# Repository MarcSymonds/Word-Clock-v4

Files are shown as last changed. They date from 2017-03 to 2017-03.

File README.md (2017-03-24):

# Word-Clock-v4
Version 4 of my Word Clock. Now uses an Arduino and WS2812 RGB LEDs.

My original Word Clock used a PICAXE microcontroller and plain white LEDs to show the time.

This version is a complete redesign and uses and Arduino Nano and WS2812B RGD LEDs to show the time in various colours.

To hold the LEDs, I used Wings3D to create a 11x5 frame to hold 55 LEDs (the clock uses 110 LEDs), and printed that on a 3D printer.

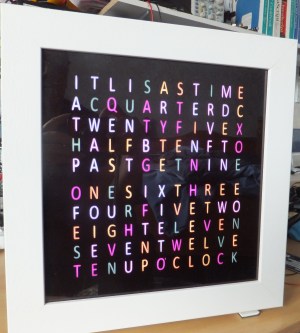
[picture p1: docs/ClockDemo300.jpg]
Clock in test mode

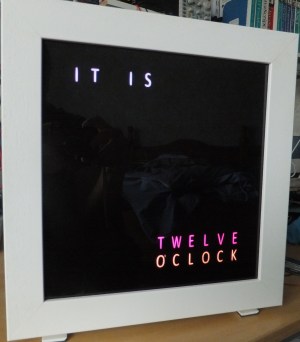
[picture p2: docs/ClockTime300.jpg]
Clock showing the current time in words

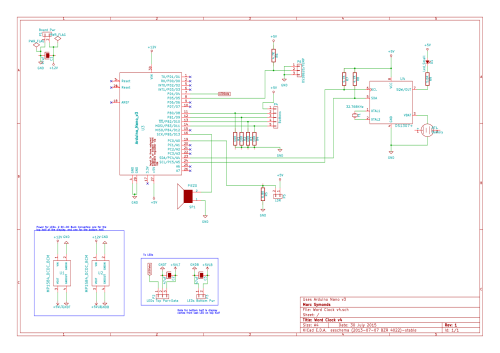
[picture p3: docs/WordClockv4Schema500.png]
KiCAD Schema


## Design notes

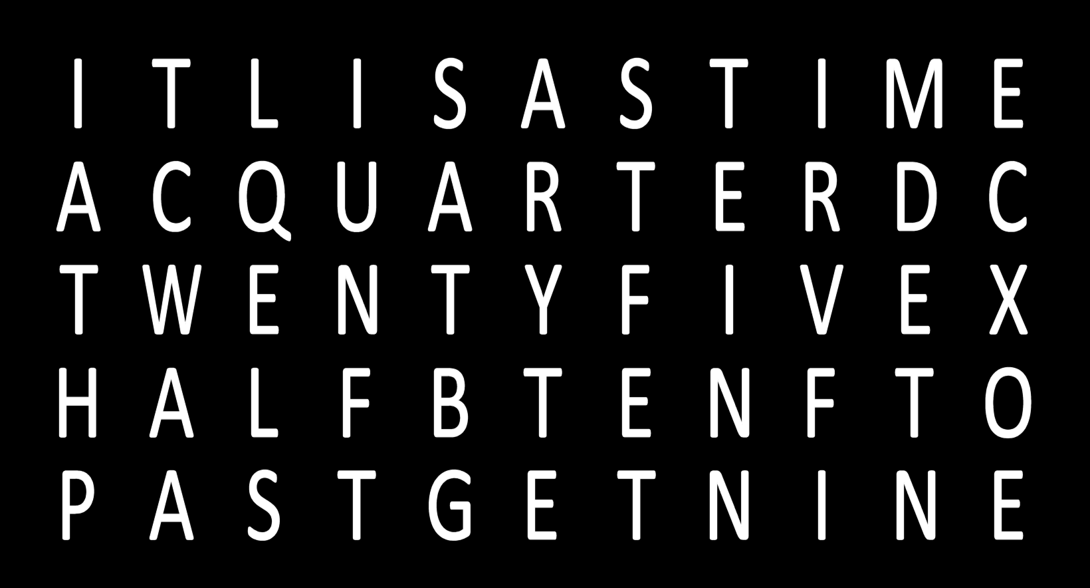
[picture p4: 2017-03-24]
Images/Word Clock mask - top.png

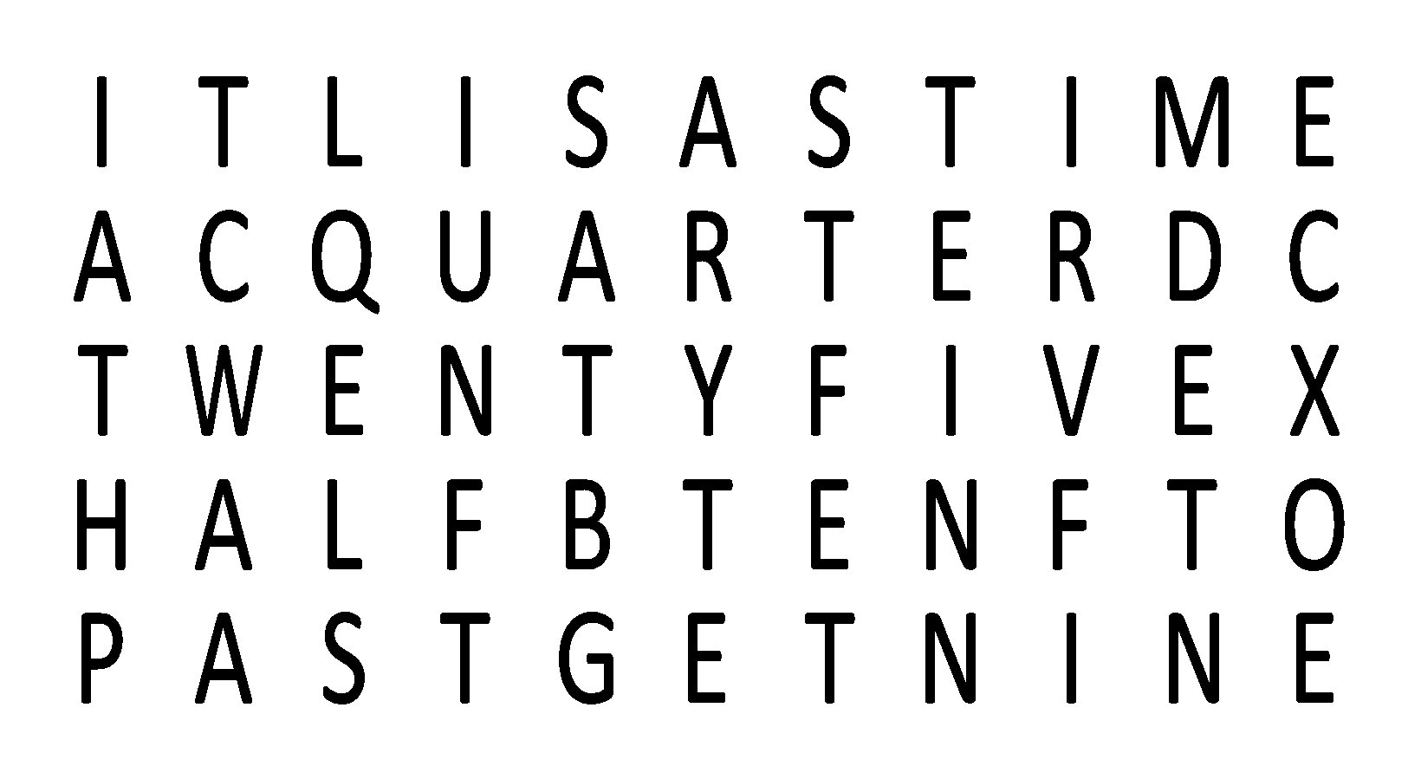
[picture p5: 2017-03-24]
Images/Word Clock mask - top.jpg

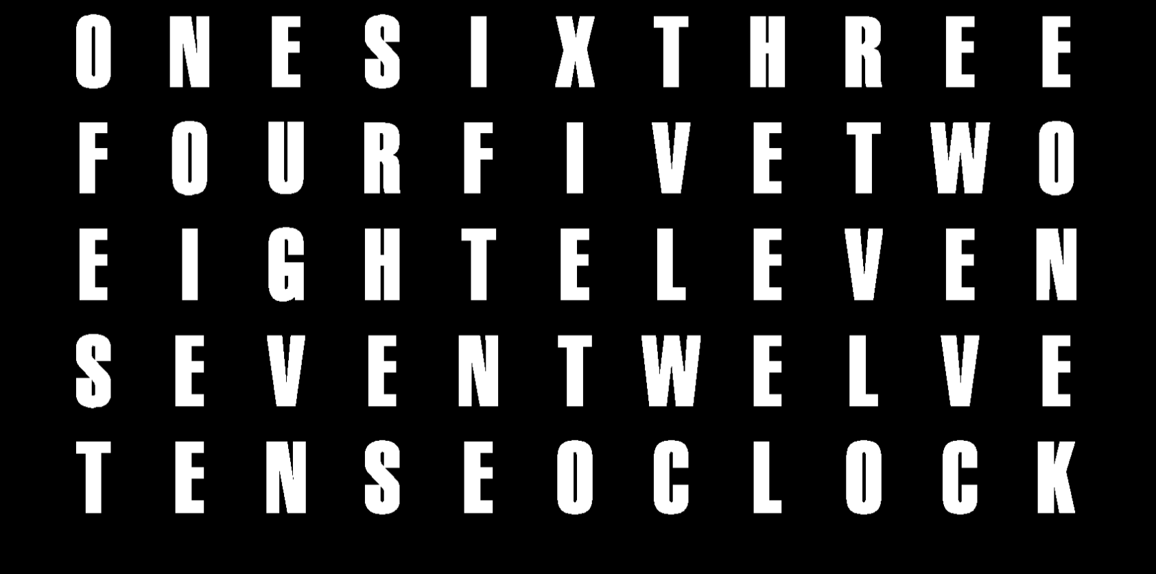
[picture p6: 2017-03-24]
Images/Word Clock mask - bottom.png

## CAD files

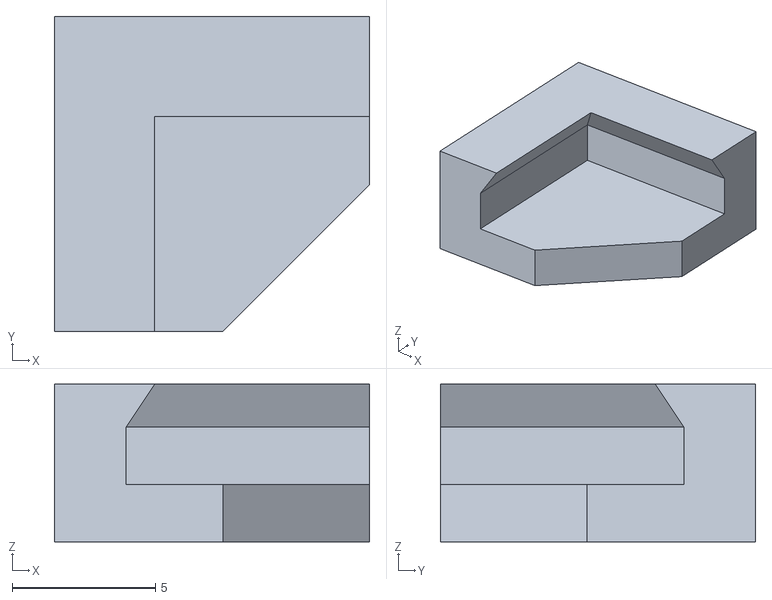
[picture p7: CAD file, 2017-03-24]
3D Objects/PCB Holder.stl
11.0 x 11.0 x 5.50

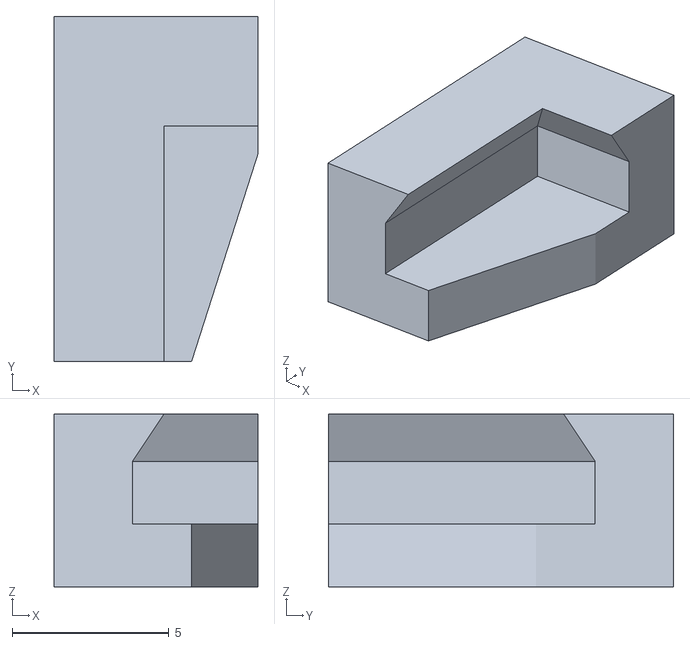
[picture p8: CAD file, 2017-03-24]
3D Objects/PCB Holder 3.stl
6.50 x 11.0 x 5.50

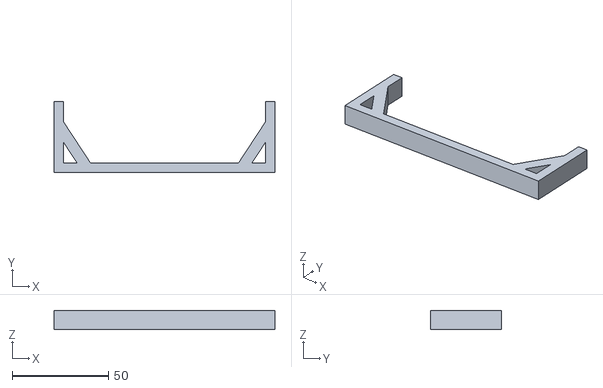
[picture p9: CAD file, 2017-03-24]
3D Objects/LED Holder Support.stl
115.0 x 37.0 x 10.0

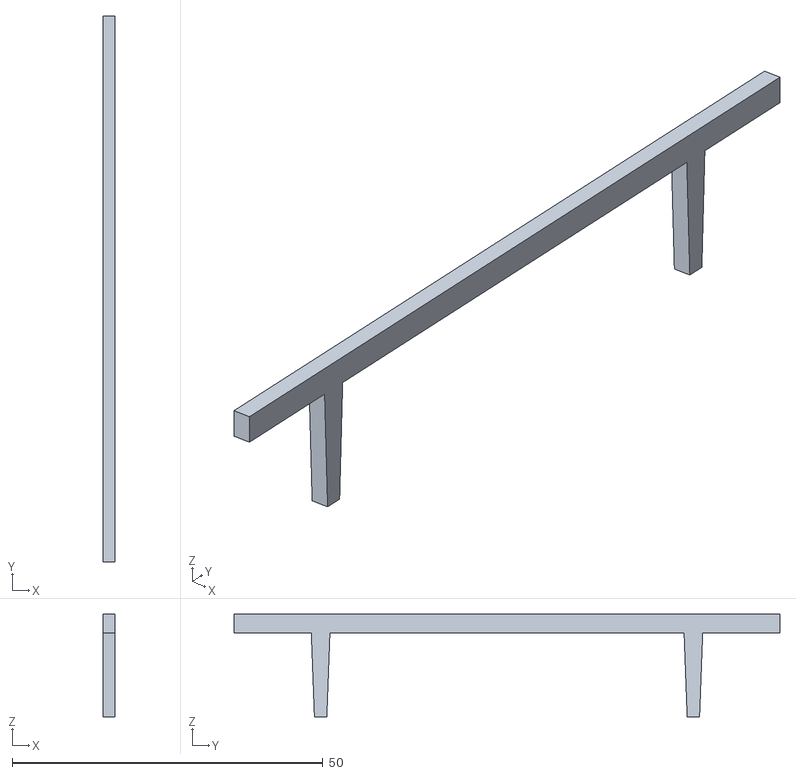
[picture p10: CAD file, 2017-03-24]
3D Objects/LED Holder - Bottom.stl
2.00 x 87.9 x 16.5

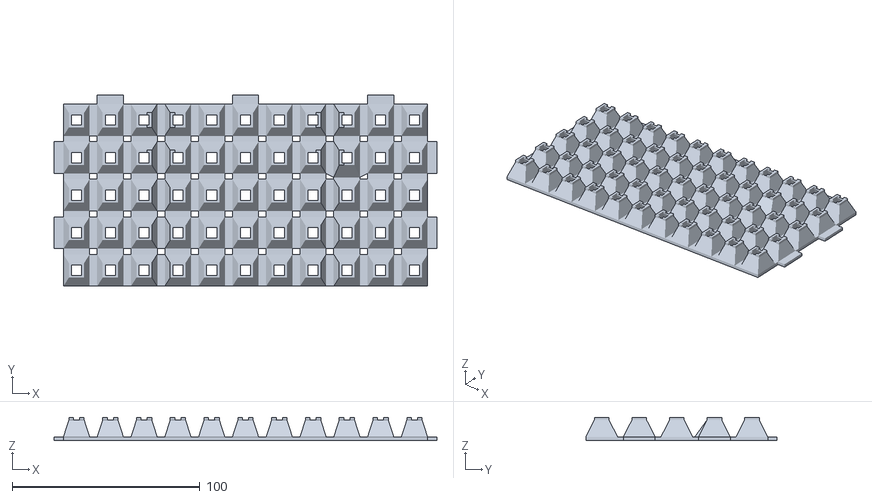
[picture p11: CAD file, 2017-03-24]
3D Objects/LED Holder - Top (Ext Q).stl
204.0 x 102.0 x 12.5

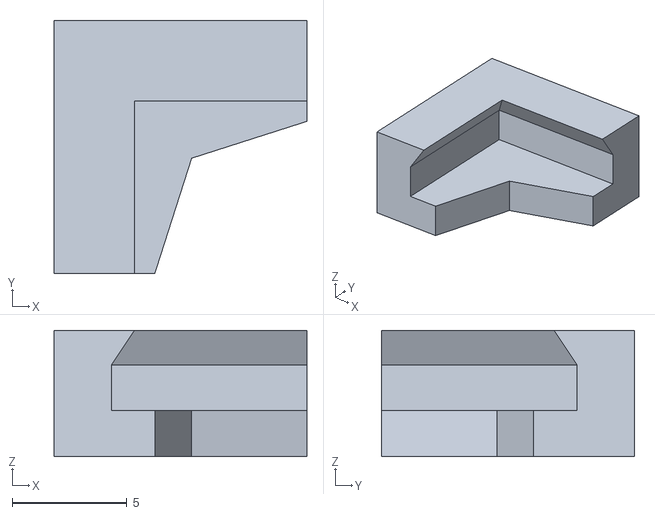
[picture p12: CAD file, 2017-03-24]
3D Objects/PCB Holder 2.stl
11.0 x 11.0 x 5.50

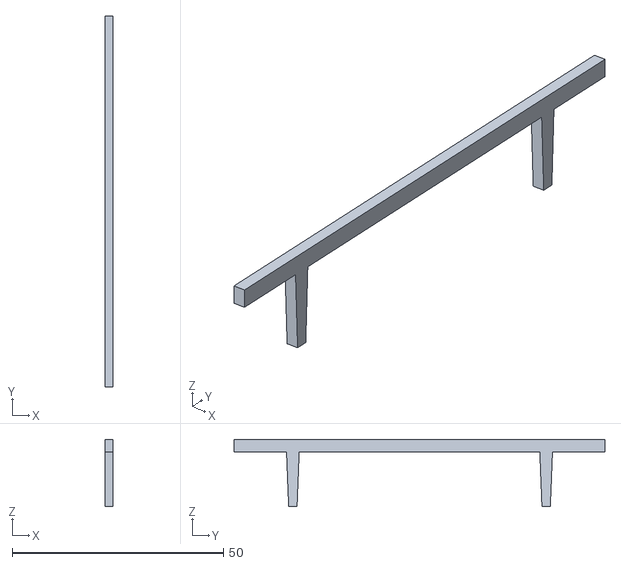
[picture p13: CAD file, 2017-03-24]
3D Objects/LED Clamp.stl
2.00 x 87.9 x 15.9

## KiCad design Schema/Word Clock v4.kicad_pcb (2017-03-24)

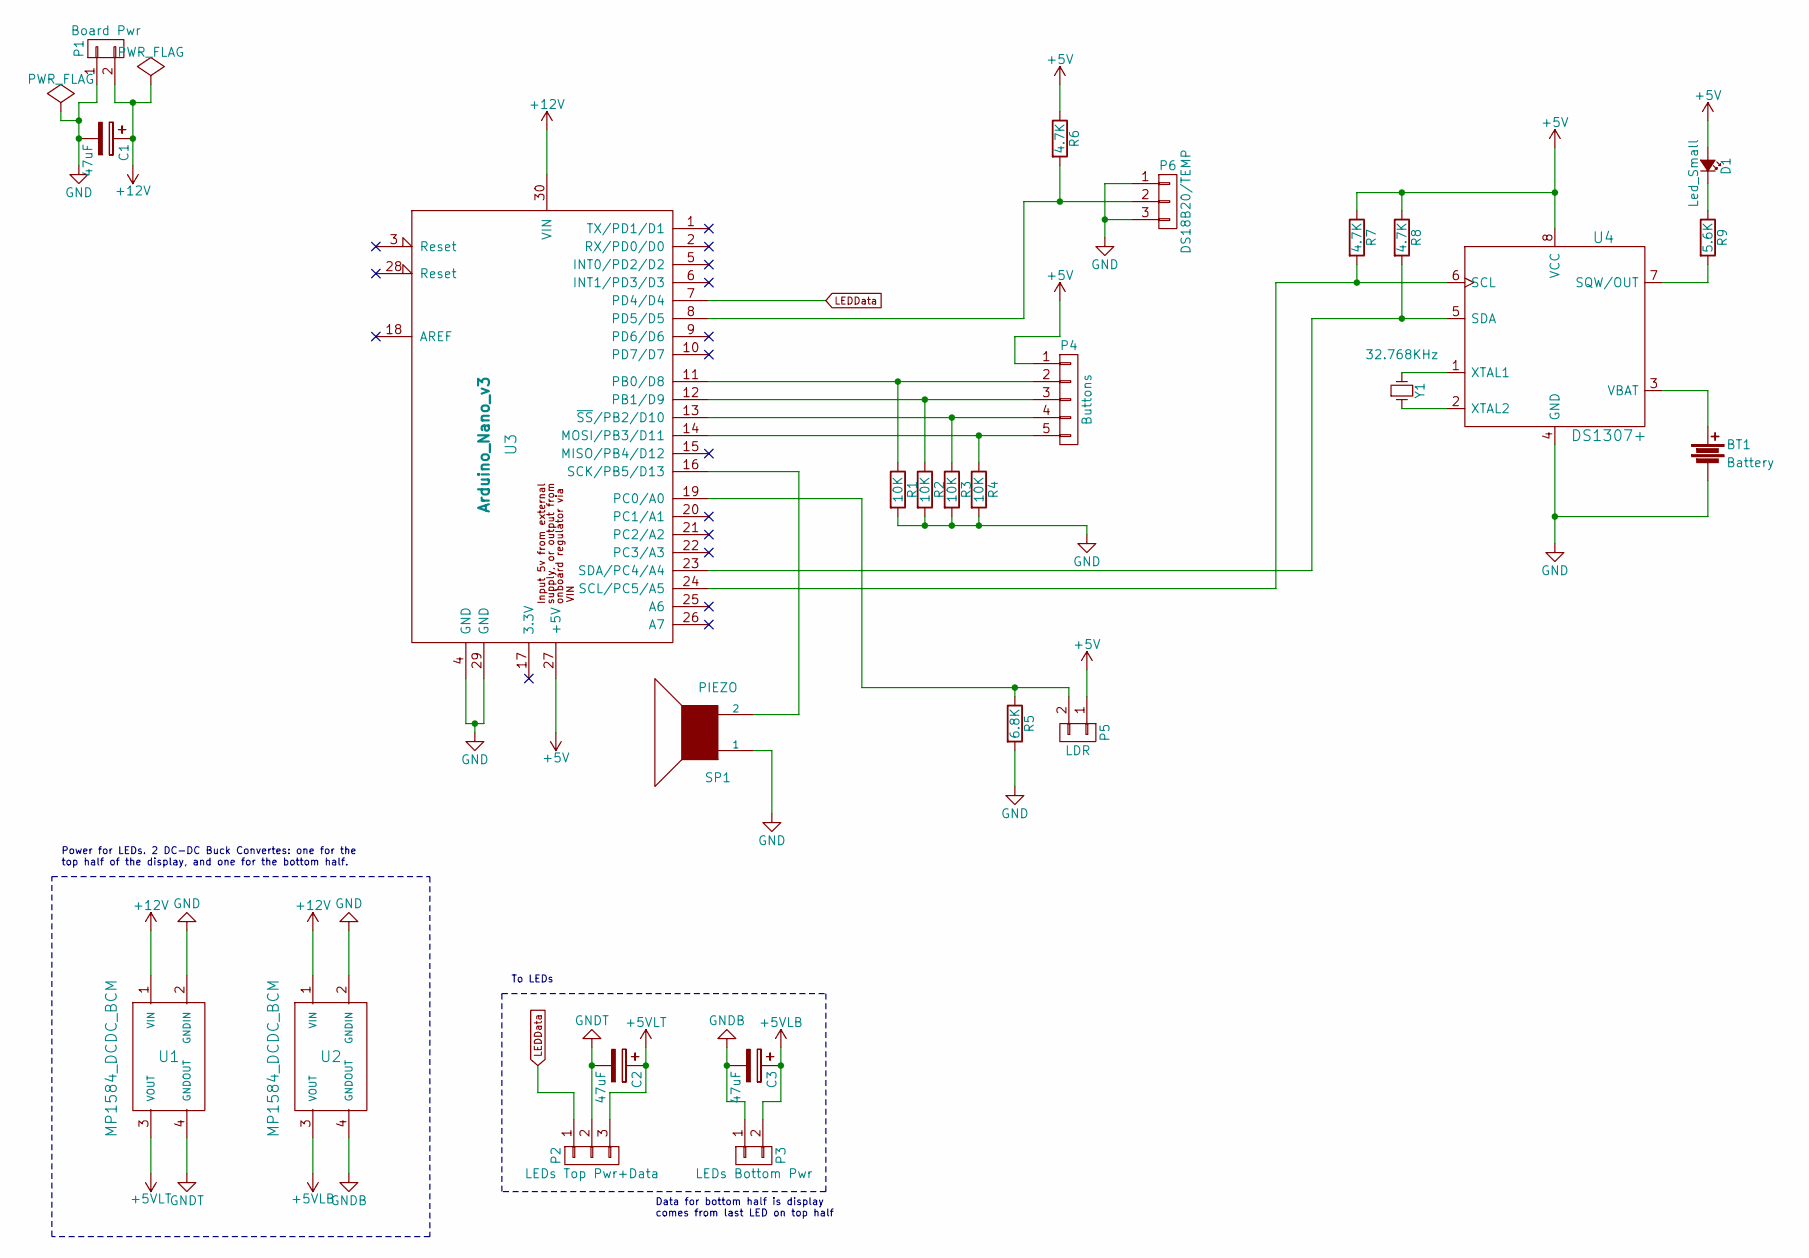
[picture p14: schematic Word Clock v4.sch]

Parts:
BT1: Battery; keystone_1025-7
C1, C2, C3: 47uF; C_Radial_D5_L11_P2.5
D1: Led_Small; LED-3MM
P1: Board Pwr; Pin_Header_Angled_1x02
P2: LEDs Top Pwr+Data; Pin_Header_Angled_1x03
P3: LEDs Bottom Pwr; Pin_Header_Angled_1x02
P4: Buttons; Pin_Header_Angled_1x05
P5: LDR; Pin_Header_Angled_1x02
P6: DS18B20/TEMP; Pin_Header_Angled_1x03
R1, R2, R3, R4: 10K; Resistor_Horizontal_RM10mm
R5: 6.8K; Resistor_Horizontal_RM10mm
R6, R7, R8: 4.7K; Resistor_Horizontal_RM10mm
R9: 5.6K; Resistor_Horizontal_RM10mm
SP1: PIEZO; Pin_Header_Angled_1x02
U1, U2: MP1584_DCDC_BCM
U3: Arduino_Nano_v3
U4: DS1307+; DIP-8_W7.62mm_LongPads
Y1: 32.768KHz; Crystal_Round_Horizontal_3mm_BigPad

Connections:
+5V: D1.1 (A), P4.1, P5.1, R6.1, R7.1, R8.1, U3.27 (+5V), U4.8 (VCC)
+5VLB: C3.1, P3.2, U2.3 (VOUT)
+5VLT: C2.1, P2.3, U1.3 (VOUT)
+12V: C1.1, P1.2, U1.1 (VIN), U2.1 (VIN), U3.30 (VIN)
GND: BT1.2, C1.2, P1.1, P6.1, P6.3, R1.2, R2.2, R3.2, R4.2, R5.2, SP1.1, U1.2 (GNDIN), U2.2 (GNDIN), U3.4 (GND), U3.29 (GND), U4.4 (GND)
GNDB: C3.2, P3.1, U2.4 (GNDOUT)
GNDT: C2.2, P2.2, U1.4 (GNDOUT)
LEDData: P2.1, U3.7 (PD4/D4)
unnamed: BT1.1, U4.3 (VBAT)
unnamed: D1.2 (C), R9.1
unnamed: P4.2, R1.1, U3.11 (PB0/D8)
unnamed: P4.3, R2.1, U3.12 (PB1/D9)
unnamed: P4.4, R3.1, U3.13 (~SS~/PB2/D10)
unnamed: P4.5, R4.1, U3.14 (MOSI/PB3/D11)
unnamed: P5.2, R5.1, U3.19 (PC0/A0)
unnamed: P6.2, R6.2, U3.8 (PD5/D5)
unnamed: R7.2, U3.24 (SCL/PC5/A5), U4.6 (SCL)
unnamed: R8.2, U3.23 (SDA/PC4/A4), U4.5 (SDA)
unnamed: R9.2, U4.7 (SQW/OUT)
unnamed: SP1.2, U3.16 (SCK/PB5/D13)
unnamed: U4.1 (XTAL1), Y1.2
unnamed: U4.2 (XTAL2), Y1.1

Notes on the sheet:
To LEDs
Power for LEDs. 2 DC-DC Buck Convertes: one for the top half of the display, and one for the bottom half.
Data for bottom half is display comes from last LED on top half

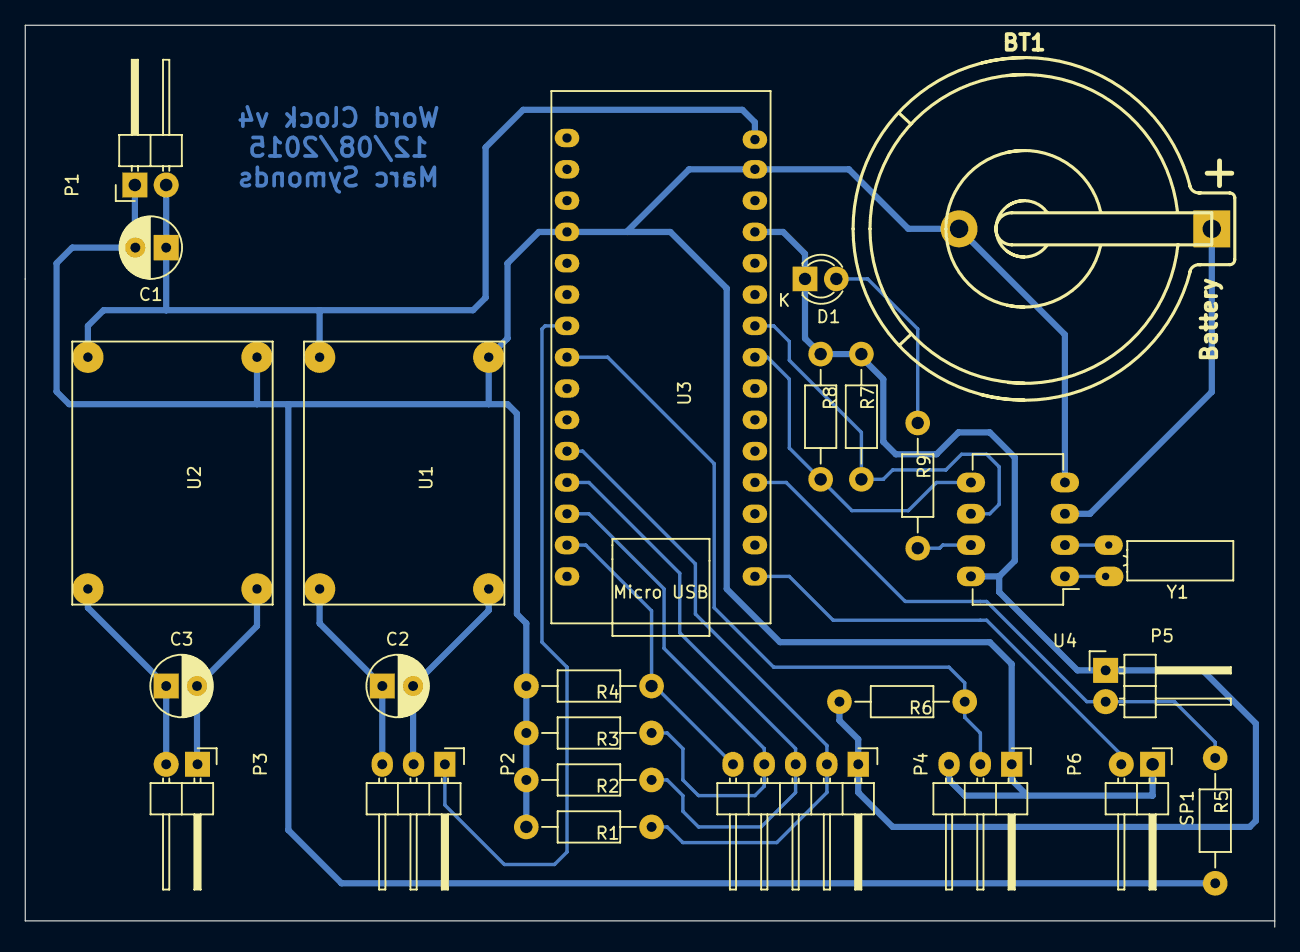
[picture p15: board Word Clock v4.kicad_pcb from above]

Board: 2 copper layers, 101.3 x 73.2 mm, 26 parts (0 on the bottom side), 22 nets.

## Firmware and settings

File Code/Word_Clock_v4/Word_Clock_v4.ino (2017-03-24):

#include <Adafruit_NeoPixel.h>
#include <BCDUtil.h>
#include <DallasTemperature.h>
#include <OneWire.h>
#include <Wire.h>
#include <DS1307.h>
#include <EEPROM.h>

#include "Global.h"
#include "DisplayValues.h"
#include "DisplayTime.h"
#include "ChangeSettings.h"
#include "DirectIO.h"

byte lastReadSecond = 99;
DisplayMode displayMode;

unsigned long currMillis;
boolean timeReset; // millis has rolled over since last read. Happens ~49.7 days.

void setup() {
  //Serial.begin(115200);
  analogReference(DEFAULT);
  
  leds.begin();
  
  Wire.begin(); // Needed for DS1307 RTC.
  tempSens.begin();
  tempSens.setResolution(10); // Don't need highest resolution for temperature sensor. Higher resolution = slower reading.
  
  rtc.changeControl(true, 0); // Enable SQWE, and set rate to 1Hz. Used for flashing LED.
  rtc.changeClockHalt(false); // Set the clock running (if not already).
  rtc.change24Hour(true); // Switch to 24 hour mode (if not already). If change occurs, the hours may change.
  
  rtc.readTime();

  // Use the current time as a seed for the random number generator.

  randomSeed(((long) rtc.getSeconds()) + (((long) rtc.getMinutes()) << 8) + (((long) rtc.getHours()) << 16));
  
  loadSettings();
}

void loop()
{
  static boolean modeInit = true;
  unsigned long time;  
  boolean refreshDisplay = false;
  boolean settingChanged = false;
  static byte changedSetting = 0;
  static unsigned long changeSettingTime = 0;
  
  (void) random(0, 255);

  time = currMillis;
  currMillis = millis();
  timeReset = (currMillis < time);
  
  readTimeAndButtons();
  
  if (buttons.readButton(BUT_SETTING))
  {
    if (changeSettings())
    {
      saveSettings();
      modeInit = true;
      refreshDisplay = true;
    }
    
    changedSetting = 0;
  }
  else
  {
    if (buttons.readButton(BUT_MODE))
    {
      switch(displayMode)
      {
        case DM_WORDS:
          displayMode = DM_HM;
          break;
        
        case DM_HM:
          displayMode = DM_MS;
          break;
          
        case DM_MS:
          displayMode = DM_TEMP;
          break;
          
        case DM_TEMP:
          displayMode = DM_TEST;
          break;
          
        default:
          displayMode = DM_WORDS;
          break;
      }
      
      saveSettings();

      modeInit = true;
      refreshDisplay = true;
      
      changedSetting = 0;
    }
    else if (buttons.readButton(BUT_BRIGHTNESS))
    {
      if (brightness > 100)
        brightness = 100;
      else if (brightness <= 1)
        brightness = 255;  // Auto brightness
      else if (brightness <= 5)
        brightness = 1;
      else
        brightness -= 5;
        
      saveSettings();
      setBackgroundTempColour();
      refreshDisplay = true;
      
      changedSetting = 1;
      settingChanged = true;
    }
    else if (buttons.readButton(BUT_ADJUST))
    {
      switch(colourMode)
      {
        case CM_SINGLE_USER:
          if (singleColourWhite)
            singleColourWhite = false;
          else
            colourMode = CM_RANDOM;
          break;
          
        case CM_RANDOM:
          colourMode = CM_SINGLE_RANDOM_FADE;
          break;
          
        case CM_SINGLE_RANDOM_FADE:
          colourMode = CM_RANDOM_FADE;
          break;
          
        default:
          colourMode = CM_SINGLE_USER;
          singleColourWhite = true;
          break;
      }
      
      saveSettings();
      
      modeInit = true;
      refreshDisplay = true;
      
      changedSetting = 2;
      settingChanged = true;
    }
    
    if (settingChanged)
    {
      saveColourRef();
      
      changeSettingTime = currMillis;

      colours[4].setColour(128, 0, 128, false);
      colours[4].brightness = 100;
  
      colours[5].setColour(192, 128, 64, false);
      colours[5].brightness = 100;
      
      clearColourRef(true, true, true);
      
      if (changedSetting == 1)
      {
        displayThing(DV_SET_Br, 0, 4);
        
        if (brightness == 255)
          displayThing(DV_AUTO, 55, 5);
        else
          displayNumber(brightness, 55, 5);
      }
      else if (changedSetting == 2)
      {
        displayThing(DV_SET_Co, 0, 4);
        
        unsigned short t;
        switch(colourMode)
        {
          case CM_SINGLE_USER:
            if (singleColourWhite)
              t = DV_COLOUR_MODE_WHITE;
            else
              t = DV_COLOUR_MODE_SINGLE_USER;
            break;
          
          case CM_RANDOM:
            t = DV_COLOUR_MODE_RANDOM;
            break;
          
          case CM_SINGLE_RANDOM_FADE:
            t = DV_COLOUR_MODE_SINGLE_RANDOM_FADE;
            break;
          
          default:
            t = DV_COLOUR_MODE_RANDOM_FADE;
            break;
        }
        
        displayThing(t, 55, 5);
      }
      else
        changedSetting = 0;
        
      updateDisplay();
    }
  
    if (changedSetting > 0)
    {
      if (timeSince(changeSettingTime) > 2000)
      {
        changedSetting = 0;
        refreshDisplay = true;

        restoreColourRef();
      }
    }
    
    if (changedSetting == 0)
    {
      if (performFades())
        refreshDisplay = true;
      
      switch(displayMode)
      {
        case DM_WORDS:
          displayWords(modeInit, refreshDisplay);
          break;
          
        case DM_HM:
        case DM_MS:
          displayHMS(modeInit, refreshDisplay);
          break;
          
        case DM_TEMP:
          displayTemp(modeInit, refreshDisplay);
          break;
          
        default:
          displayTest(modeInit, refreshDisplay);
          break;
      }
      
      modeInit = false;
    }
  }
  
  readLightAndTemp(false);
}

boolean performFades()
{
  static unsigned long brightnessAdjTime = 0;
  boolean colourChanged = false;
  Colour *c;
  int i;
  unsigned long newColour;
  unsigned long brightnessTime;
  unsigned long brightlevel;
  boolean brightnessAdj;
  
  if (timeReset)
    brightnessAdjTime = 0;

  brightnessTime = timeSince(brightnessAdjTime);
  brightnessAdj = (brightnessTime >= 200);
  
  brightlevel = (brightness == 255) ? llBrightness : brightness;
  
  for (i = 0; i < COLOURCTRLS; i++)
  {
    c = &colours[i];
      
    if (brightnessAdj)
    {
      if (c->brightness > brightlevel)
        --c->brightness;
      else if (c->brightness < brightlevel)
        ++c->brightness;
    }

    if (c->fader)
      c->fadeColour();
        
    newColour = c->getColour();
    if (newColour != c->prevColour)
    {
      colourChanged = true;
      c->prevColour = newColour;
    }
  }

  if (brightnessAdj)
    brightnessAdjTime = currMillis + 200;

  return colourChanged;
}

void readTimeAndButtons()
{
  buttons.scanButtons();
  rtc.readTime();
}

void readLightAndTemp(boolean forceLight)
{
  boolean secondPast = false;
  byte val;
  float temp;
  
  val = rtc.getSeconds(true);
  if (lastReadSecond != val)
  {
    secondPast = true;
    lastReadSecond = val;
  }

  if (forceLight || secondPast && (val % 10) == 0)
  {
    // Read light level and temp every 10 seconds. These calls are relatively slow.

    lightLevel = analogRead(0);
  
    #define LLB_MIN 30
    #define LLB_MAX 80
    llBrightness = (lightLevel / (1024 / (LLB_MAX - LLB_MIN))) + LLB_MIN;

    tempSens.requestTemperatures();

    temp = tempSens.getTempFByIndex(0);
    if (temp > -10.0)
      tempF = temp;
    
    temp = tempSens.getTempCByIndex(0);
    if (temp > -10.0)
      tempC = temp;
    
    setBackgroundTempColour();
  }
}

void setBackgroundTempColour()
{
  //float temp;
  short temp;
  
  temp = (short)tempSens.getTempCByIndex(0) / 5;

  if (temp < 0)
    temp = 0;
  else if (temp > 5)
    temp = 5;
  
  tempColourR = (byte)(temp * (brightness == 255 ? llBrightness : brightness) / 100);
  tempColourB = (byte)((5 - temp) * (brightness == 255 ? llBrightness : brightness) / 100);
  
  if (tempColourR == 0 && tempColourB == 0)
  {
    if (temp < 3)
      tempColourB = 1;
    else
      tempColourR = 1;
  }
}

/*float diff(float a, float b)
{
  if (a > b)
    return a - b;
  else
    return b - a;
}*/

// We will use the RAM of the DS1307 to save some of the settings if power is lost.

void saveSettings()
{
  byte buf[9];
  
  buf[0] = 0x55; // Header to indicate what is read back are the settings.
  buf[1] = displayMode;
  buf[2] = brightness;
  buf[3] = colourMode;
  buf[4] = singleColour;
  buf[5] = singleColourWhite ? 1 : 0;
  buf[6] = tempBackground ? 1 : 0;
  buf[7] = fadeSpeed;
  buf[8] = showTempF ? 1 : 0;
  
  rtc.writeData(DS1307_RAM, buf, 9);
}

void loadSettings()
{
  byte buf[9];
  
  rtc.readData(DS1307_RAM, buf, 9);

  if (buf[0] == 0x55)
  {
    displayMode = (DisplayMode)buf[1];
    brightness = buf[2];
    colourMode = (ColourMode)buf[3];
    singleColour = buf[4];
    singleColourWhite = (buf[5] != 0);
    tempBackground = (buf[6] != 0);
    fadeSpeed = (RandomMode) buf[7];
    showTempF = (buf[8] != 0);
  }
}

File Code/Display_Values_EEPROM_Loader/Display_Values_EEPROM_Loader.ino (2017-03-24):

#include <EEPROM.h>

byte data[] = {
    // Digits.
    
    0+128, 3, 11, 13, 22, 24, 33, 35, 44+128, 3, 255,                                                    //   0 - 11  Zero
    1, 11, 12, 23, 34, 44+128, 3, 255,                                                                   //  11 -  8  One
    0+128, 3, 13, 22+128, 3, 33, 44+128, 3, 255,                                                         //  19 -  9  Two
    0+128, 3, 13, 22+128, 3, 35, 44+128, 3, 255,                                                         //  28 -  9  Three
    0, 2, 11, 13, 22+128, 3, 35, 46, 255,                                                                //  37 -  9  Four
    0+128, 3, 11, 22+128, 3, 35, 44+128, 3, 255,                                                         //  46 -  9  Five
    0+128, 3, 11, 22+128, 3, 33, 35, 44+128, 3, 255,                                                     //  55 - 10  Six
    0+128, 3, 13, 24, 35, 46, 255,                                                                       //  65 -  7  Seven
    0+128, 3, 11, 13, 22+128, 3, 33, 35, 44+128, 3, 255,                                                 //  72 - 11  Eight
    0+128, 3, 11, 13, 22+128, 3, 35, 44+128, 3, 255,                                                     //  83 - 10  Nine
    
    // Setting labels
    
    0, 3, 11, 14, 22+128, 4, 33, 36, 44, 47, 49, 38, 27, 17, 18, 255,                                    //  93 - 16  Hr
    0, 4, 11, 12, 14, 15, 22, 24, 26, 33, 37, 44, 48, 50, 39, 28, 6, 255,                                // 109 - 18  Mi
    0, 4, 11, 15, 22, 24, 26, 33, 34, 36, 37, 44, 48, 8, 19, 28+128, 3, 39, 41, 50+128, 3, 255,          // 127 - 22  Wd
    0+128, 3, 11, 14, 22, 25, 33, 36, 44+128, 3, 16, 18, 27, 29, 39, 49, 255,                            // 149 - 17  Dy
    0, 4, 11, 12, 14, 15, 22, 24, 26, 33, 37, 44, 48, 17+128, 3, 28, 30, 39, 41, 50+128, 3, 255,         // 166 - 22  Mo
    0, 4, 12, 14, 24, 35, 46, 49, 38, 27, 17, 18, 255,                                                   // 188 - 13  Yr
    0+128, 3, 11, 14, 22+128, 3, 33, 36, 44+128, 3, 16+128, 3, 28, 39, 50, 255,                          // 201 - 16  Bt Background Temp
    0+128, 3, 11, 22, 33, 44+128, 3, 15+128, 3, 26, 28, 37, 39, 48+128, 3, 255,                          // 217 - 16  Co Colour
    0+128, 3, 11, 22, 23, 33, 44, 15+128, 3, 26, 28, 37, 38, 39, 48, 50, 255,                            // 233 - 17  Fa Fade
    0+128, 3, 12, 23, 34, 45, 15+128, 3, 26, 37, 38, 48, 255,                                            // 250 - 13  Tf Temp display F (or C)
    
    // Other
    
    0+128, 3, 11, 22, 33+128, 3, 255,                                                                    // 263 -  7  Small C
    0+128, 3, 11, 22, 23, 33, 255,                                                                       // 270 -  7  Small F
    0+128, 3, 255,                                                                                       // 277 -  3  - (hyphen)

    // Weekdays = Monday can use the Mo from Settings above.    

    0+128, 3, 12, 23, 34, 45, 15, 17, 26, 28, 37, 39, 48+128, 3, 255,                                    // 280 - 15   Tu
    0, 4, 11, 15, 22, 24, 26, 33, 34, 36, 37, 44, 48, 6+128, 3, 17, 28, 29, 39, 50+128, 3, 255,          // 295 - 22   We
    0+128, 3, 12, 23, 34, 45, 15, 26+128, 3, 37, 39, 48, 50, 255,                                        // 317 - 14   Th
    0+128, 3, 11, 22, 23, 33, 44, 48, 37, 26, 16, 17, 255,                                               // 331 - 13   Fr
    0+128, 3, 11, 22+128, 3, 35, 44+128, 3, 15+128, 3, 26, 28, 37+128, 3, 48, 50, 255,                   // 344 - 17   Sa
    0+128, 3, 11, 22+128, 3, 35, 44+128, 3, 15, 17, 26, 28, 37, 39, 48+128, 3, 255,                      // 361 - 17   Su
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

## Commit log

2026-11-11 Added microPassed() and millisPassed() that also check for when these counters roll-over.
    Added vars to handle DST.
2026-11-11 Updated schema and PCB layout so that I could get a proper PCB produced by PCBWay.
2026-11-11 Update README to fix LED driver model, and insert images.
    Corrected the LED driver model from MAX7218 to MAX7219.
